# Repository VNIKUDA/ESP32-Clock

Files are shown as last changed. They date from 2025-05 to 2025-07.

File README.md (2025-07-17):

#  ESP32 CLOCK

> This project was made with **PlatfornIO** VSCode extension. If you're using **Arduino IDE**, please copy code from `src/main.py`.

This project was attempt to reverse engineer this clock and recreate my version using ESP32 microcontroller.

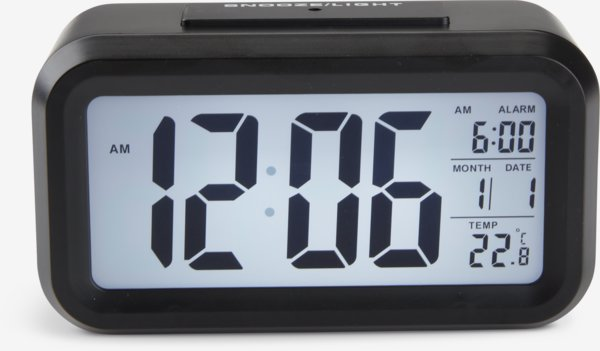
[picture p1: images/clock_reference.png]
Clock reference image


And here is my version:
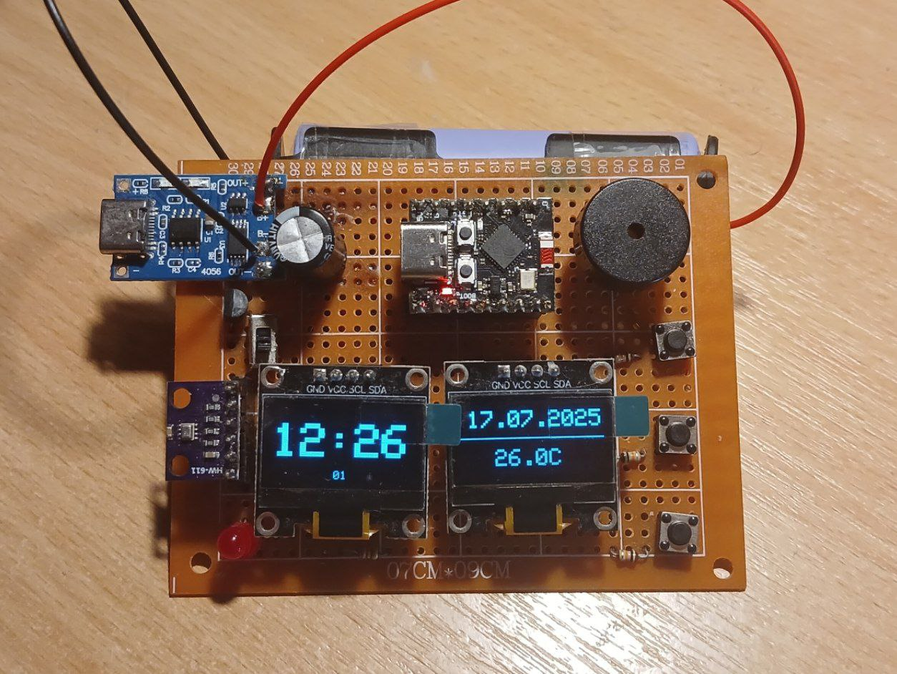
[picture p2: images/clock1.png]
Clock

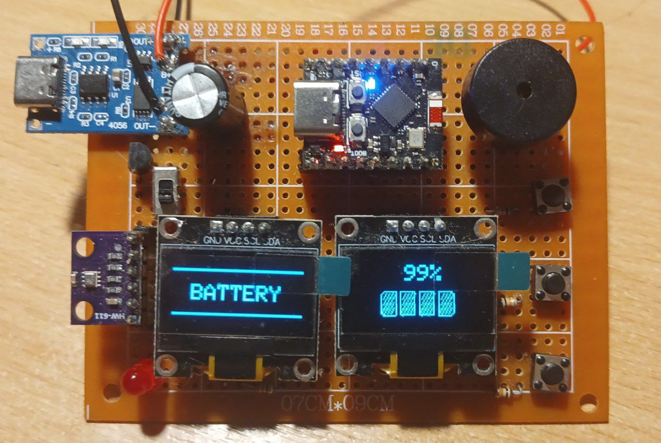
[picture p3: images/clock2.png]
Clock

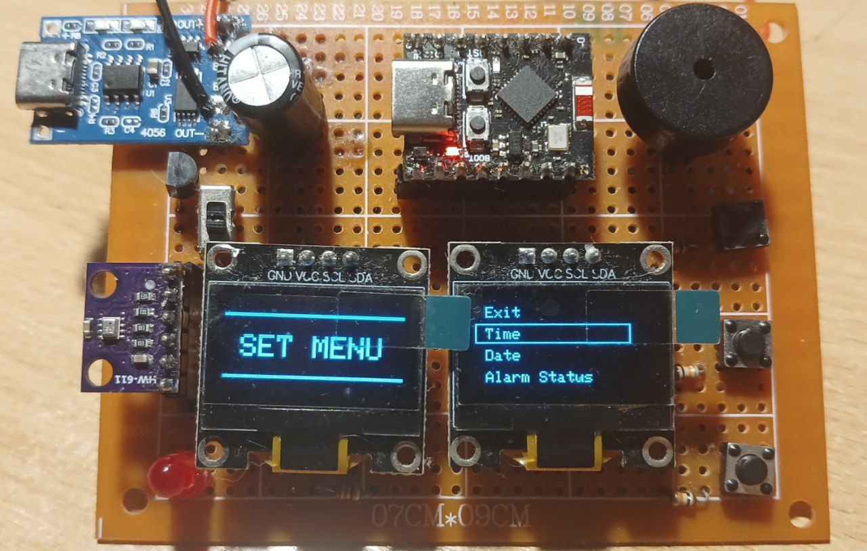
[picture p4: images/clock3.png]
Clock

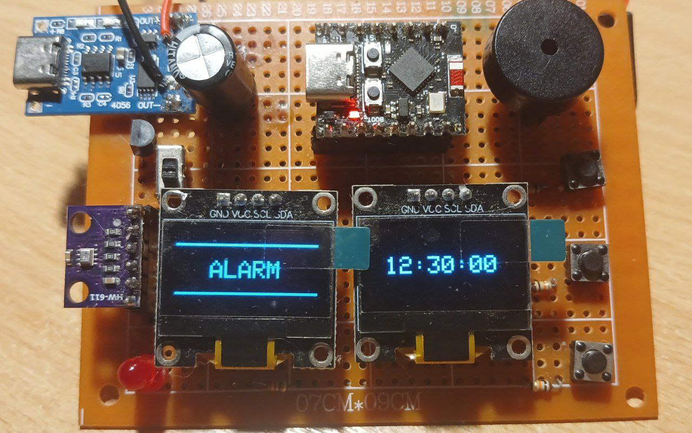
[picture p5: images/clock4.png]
Clock

It may look not as pretty as reference, but it works just as the other and has additional features!

## What functionality does it have?
 - **Three buttons for controll**: UP, SET, DOWN.

 - **Charging module**. While charging the red indicator will light up. Once charge, the red one will turn off and green will light up instead.

 - **Showing time and date**.

 - **Reading temperature** in the room/surrounding area.

 - **Alarm**. It will play a little alarm sound where the time comes.

 - **Sleep**. To preserve battery and not to annoy you with bright light during your sleep, you can set time when clock will go into sleep. You can still check time by waking up using SET button and screen will show the time for 10 seconds.

 - **Settings menu**. Here you can:
    - Set current time and date
    - Set alarm time and turn it off/on
    - Set sleep start and end time + turn on/off the sleep.
    - Turn on or off seconds displayment
    - Check battery charge (aproximate)

 **NOTE**: PLEASE DON'T PLUG CHARGING MODULE AND ESP32 USB-C PORT AT THE SAME TIME! IT WILL CAUSE DAMAGE TO THE CHIP!<br/>
## Technical specifications
 - **Current draw**: **~8 mA** in normal mode and **~0.07 mA** in sleep/
 - **Battery**: 18650 3.7V Li-on battery. 
 - **Battery capacity**: 2000mAh (but you can change to your needs).
 - **Time between charging**: **~8 days** and **~12.5** days using sleep mode for 9 hours a day.
 - **Time drift**: clock losses **1 minute each 5 days**.

**NOTE**: Because this clock doesn't uses external RTC module, it has unavoidable time drift. Please be aware.

## Requirenments
 | Part | Quantity |
 | -----|:-------:|
 | ESP32-C3 SUPER MINI | 1 |
 | SSD1306 OLED 128x64 display | 2 |
 | BMP280 HW-611 sensor | 1 |
 | TP4056 charging module | 1 |
 | 18650 3.7V 2000mAh battery | 1 |
 | 18650 battery case | 1 |
 | Buzzer | 1 |
 | Red LED | 1 |
 | Push-button | 3 |
 | Slide-switch | 1 |
 | 10kOm Resistor | 5 |
 | 220Om Resistor | 1 |
 | HT7833 3.3V TO-92 LDO | 1 |
 | 1000uF Electrolytic capacitor | 1 |
 | 100nF Ceramic capacitor | 1 |

 **Optional:** You can use female pin header to connect esp32, displays sensor and buzzer to be able to reuse this assets in other projects or to replace if something fails. You can buy a one or two 40-pin one and chop it to pieces of all sizes you need or buy this female pin connectors.
 |Part | Quantity|
 |-----|:-------:|
 | 1-pin female pin connector | 2 |
 | 4-pin female pin connector | 2 |
 | 6-pin female pin connector | 1 |
 | 8-pin female pin connector | 2 |

 1-pin are used for Buzzer, 4-pin for displays, 6-pin for temperature sensor and 8-pin for esp32.

## Schematic
Here you can download <a download href="./Clock_Alarm.fzz">fritzing schematic</a> to build clock yourself.

**Schematic**
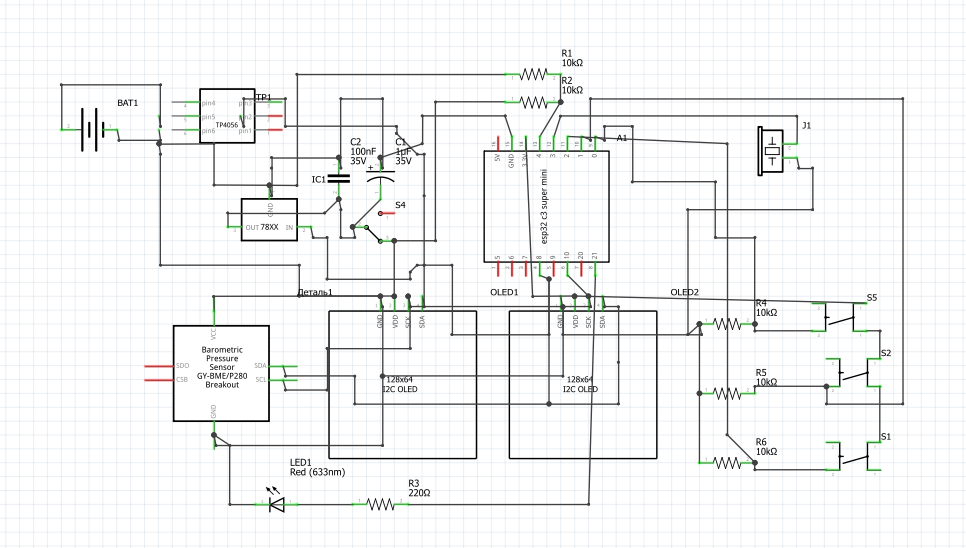
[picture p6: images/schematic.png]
Schematic


**Prototype view**
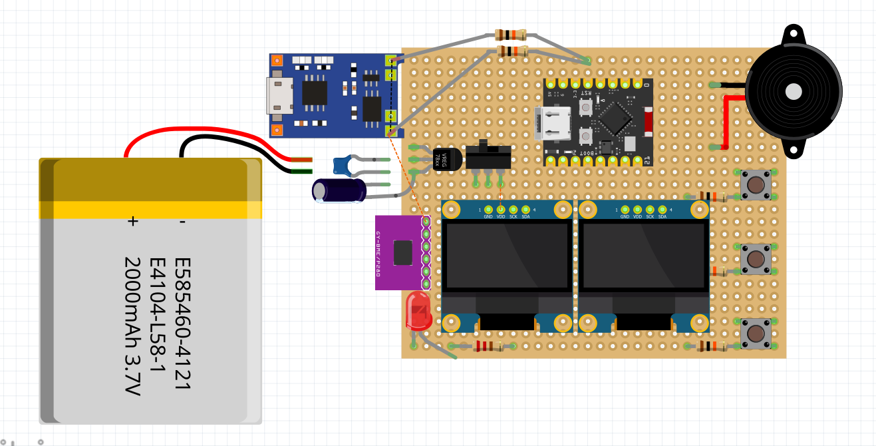
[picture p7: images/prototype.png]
Prototype view


**Prototype view with wires**
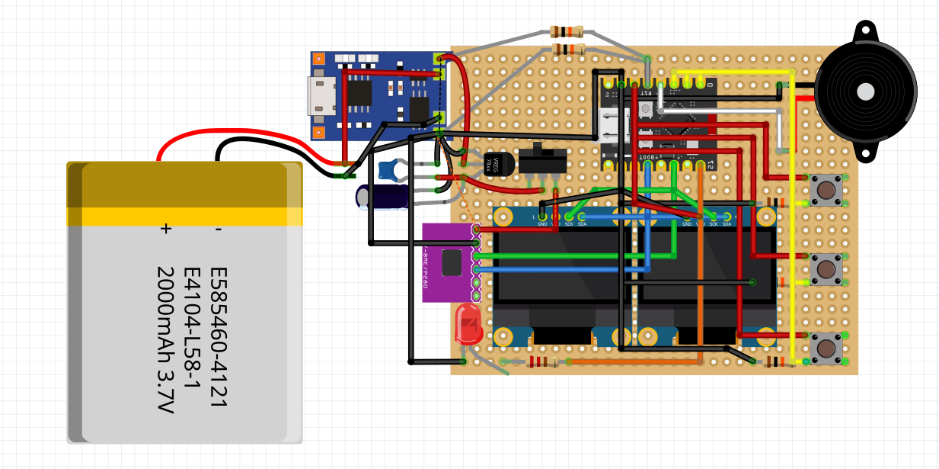
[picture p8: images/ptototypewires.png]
Prototype view with wires


**ESP32 C3 SUPER-MINI PINOUT**
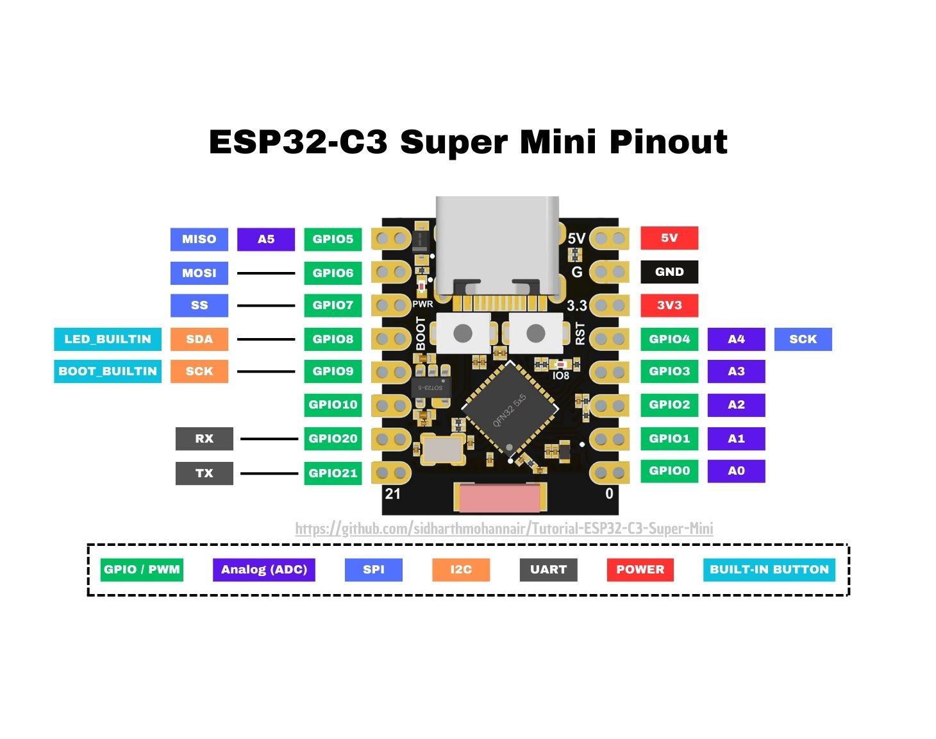
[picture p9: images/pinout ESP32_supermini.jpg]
Pinout


----

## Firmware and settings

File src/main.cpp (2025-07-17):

// --------- ГОДИННИК ---------
//
// Що він може?
//    У годинника є три екрани: годинник, меню та налаштування.
//    Є будильник з сигналом. Можна налаштовувати час, дату, час будильника та
//    його стан (включений або виключений) і багато іншого
//
// Як вийти в меню?
//    Щоб потрапити на екран меню треба затиснути кнопку SET.
//    Звідти можна виконати наступні дії:
//      - Повернутись на годинник, тобто вийти з меню.
//      - Налаштувати поточний час
//      - Налаштувати поточну дату
//      - Налаштувати статус будильника
//      - Налаштувати час будильника
//      - Налаштувати статус режима сну
//      - Налаштувати початок сну
//      - Налаштувати кінець сну
//      - Налаштувати відображення секунд
//      - Подивитись заряд батареї
//    Між діями можна переміщатись на кнопки UP та DOWN.
//    Щоб підтвердити будь-яку дію в меню треба затиснути кнопку SET.
//    Після вибору дії вас перенесе не меню налаштування (або на годинник
//    якщо ви вибрали вийти).
//
// Як подивитись час в режимі сну?
//    Для цього натисніть на кнопку SET, і екран покаже вам 
//    час на момент включення протягом 10 секунд, після чого годинник знову засне.
// 
// 
// ----------------------------

// Бібліотеки
#include <Adafruit_SSD1306.h>
#include <Adafruit_BMP280.h>
#include <Wire.h>
#include <esp_pm.h>

// Змінні для відстеження зміни часу
long currentTime, previousTime;

// Мілісекунд в секунді
#define MILLI_TO_SECOND 1000.0
#define MICRO_TO_SECOND 1000000.0

// Через шуми та неідеальності в кварцовому резонаторі, функція millis()
// дуже відстає від реального часу. Тому в випадку використання
// годинника без зовнішього RTC модуля використовуються мултіплаєри щоб
// приблизно отримати реальний час. На жаль, дрифт буде присутнім завжди.
// При цих налаштувань годинник відстає на 1 хвилину через 4.5 днів.
// Використовувався алгоритм двійкового пошуку для знаходження оффсетів.
#define TIME_OFFSET 1.002181676275
#define SLEEP_TIME_OFFSET 1.00268167625

// Заряд батареї та її напруга (приблизна)
float voltage = 0;
int charge = 0;

#define DISCHARGED_BATTERY_VOLTAGE 3.3
#define CHARGED_BATTERY_VOLTAGE 4.1

// Режим (годинник + будильник, вибір налаштування, меню налаштування)
int mode;

// Поточна температура
String temperature;

// Налаштування будильника
bool alarm_on = true;
bool alarm_playing = false;
int alarm_hours = 7, alarm_minutes = 30, alarm_seconds = 0;

// Налаштування часу відключення
bool sleep_on = true;
bool sleeping = false;
int sleep_start_hours = 12, sleep_start_minutes = 0, sleep_start_seconds = 5;
int sleep_end_hours = 12, sleep_end_minutes = 0, sleep_end_seconds = 30; 

// Налаштування поточного часу годинника
float hours = 12, minutes = 0, seconds = 0;

// Налаштування для відображення секунд
bool display_seconds = false;

// Налаштування поточної дати
int date = 17, month = 7, year = 2025;

// Список днів в кожному місяці (для лютого йде перевірка в коді)
int monthDays[] = {
    31, // Січень
    28, // Лютий
    31, // Березень
    30, // Квітень
    31, // Травень
    30, // Червень
    31, // Липень
    31, // Серпень
    30, // Вересень
    31, // Жовтень
    30, // Листопад
    31  // Грудень
};

// Список налаштувань та дій для меню вибору налаштування
String options[] = {
    "Battery", "Display Seconds", "Sleep End", "Sleep Start", "Sleep Status", "Alarm Time", "Alarm Status", "Date", "Time", "Exit"};
int options_count = sizeof(options) / sizeof(String);
int menu_option = options_count - 1; // Поточний вибір
int option_cursor = options_count - 1; // Індекс найвищої опції на екрані

// Список полів для кожного меню налаштування
float *timeFields[] = {&hours, &minutes, &seconds};
int *dateFields[] = {&date, &month, &year};
int *alarmFields[] = {&alarm_hours, &alarm_minutes, &alarm_seconds};
int *sleepStartFields[] = {&sleep_start_hours, &sleep_start_minutes, &sleep_start_seconds};
int *sleepEndFields[] = {&sleep_end_hours, &sleep_end_minutes, &sleep_end_seconds};

int fieldCount[] = {0, 1, 3, 3, 1, 3, 1, 3, 3}; // Кількість полів на кожному меню налаштування
int current_field = 0;           // Поточне поле налаштування

// Поріг зарахування натиску кнопки на певну дію
#define MENU_ACTIVATION_THRESHOLD 1000 // Час для викликання SET MENU та підтвердження вибору\налаштувань
#define ACTION_THRESHOLD 100           // Час для зарахування натиску кнопки

// Клас кнопки (для легшості роботи з ними та зменшеню повторення коду)
class Button
{
private:
    int pin; // Цифровий порт, до якого підключена кнопка

    bool clicked = false; // Чи кнопка натиснута (тільк перший раз)
    bool hold = false;    // Чи кнопка затиснута
    bool pressed = false; // Чи кнопка натиснута (взагалі)
    int pressedTime = 0;  // Час з початку натиску кнопки в мілісекундах

    int action = LOW;       // Сигнал з цифрового порта
    int lastAction = LOW;   // Минулий сигнал з цифрового порта
    int lastActionTime = 0; // Час минулої зміни сигналу з цифрового порта

public:
    // Конструктор. Приймає цифровий порт, до якого приєднана кнопка
    Button(int pin)
    {
        this->pin = pin;
    };

    // Ініціалізація кнопки шляхом встановлення режиму роботи порта на вхід\зчитування
    void init()
    {
        pinMode(pin, INPUT);
    }

    // Оновлення данних про кнопку
    void update()
    {
        // Читання поточного сигналу з цифрового порта
        action = digitalRead(this->pin);

        // Якщо сигнал відрізняється від попереднього, то оновити час останої дії
        // кнопки та останього сигналу.
        if (action != lastAction)
        {
            lastAction = action;
            lastActionTime = currentTime;
        }

        // Якщо поточний сигнал високий (тобто кнопка затиснута) і час з останьої дії
        // є більшим за час для зарахування натиску
        if (action == HIGH && currentTime - lastActionTime >= ACTION_THRESHOLD)
        {

            // Якщо це вже друга обробка, то кажемо що кнопка вже затиснута, а не натиснута
            // перевіряти коли кнопка була натиснута, а не затиснута
            if (this->hold == false && this->clicked == true)
            {
                this->hold = true;
                this->clicked = false;
            }
            // Перевіряємо чи це перша обробка, для того щоб мати змогу
            if (this->pressed == false && this->clicked == false)
            {
                this->clicked = true;
                this->hold = false;
            }

            // Кажемо, що кнопка взагалі натиснута (не важливо чи затиснута чи натиснута вперше)
            this->pressed = true;
        }
        // Якщо ні, то кажемо що кнопка взагалі не натиснута і час натиску відповідно
        // дорівнює 0
        else
        {
            this->pressed = false;
            this->pressedTime = 0;
            this->hold = false;
            this->clicked = false;
        }

        // Якщо конпка взагалі натиснута, то відслідковуємо час скільки вона є натиснутою
        if (this->pressed)
        {
            pressedTime = currentTime - lastActionTime;
        }
    }

    // Методи-інтерфейс для отримання данних з кнопки

    bool getPressed()
    {
        return this->pressed;
    }

    int getPressedTime()
    {
        return this->pressedTime;
    }

    bool getClicked()
    {
        return this->clicked;
    }

    bool getHold()
    {
        return this->hold;
    }

    int getPin() {
        return this->pin;
    }

    // Скидання стану кнопки, крім стану натиску взагалі. Використовується для
    // того, щоб, наприклад, коли користувач затиснув на вихід в меню його одразу не
    // перекинуло назад в меню (якщо стан затиску і час натиску залишиться такими ж,
    // тоді програма подумає що користувач спеціально затиснув кнопку на екрані годиника
    // і хоче в меню)
    void reset()
    {
        this->pressedTime = 0;
        this->hold = false;
        this->clicked = false;
    }
};

// ДисплеЇ
Adafruit_SSD1306 leftOled(128, 64, &Wire);
Adafruit_SSD1306 rightOled(128, 64, &Wire);

// Датчик температури
Adafruit_BMP280 bmp;

// Кнопки
Button upButton(0);
Button setButton(1);
Button downButton(2);

#define PIEZO 3 // Цифровий порт для пієзодинаміка
#define CHARGE_LED 21

// Функція для відмальовки вертикальної стрілки
void drawVArrow(int x, int y, int w, int h, int thickness, int direction, Adafruit_SSD1306 *display, int color = WHITE)
{
    for (int i = 0; i < thickness; i++)
    {
        if (direction == 1)
        {
            display->drawLine(x, y + h + i, x + w / 2, y + i, color);
            display->drawLine(x + w / 2, y + i, x + w, y + h + i, color);
        }
        else
        {
            display->drawLine(x, y + i, x + w / 2, y + h + i, color);
            display->drawLine(x + w / 2, y + h + i, x + w, y + i, color);
        }
    }
}

// Функція відмальовки наполовину закругленого прямокутника
void drawRoundRect(int x, int y, int w, int h, int rounding, int direction, Adafruit_SSD1306 *display, int color = WHITE) {
    if (direction == 1) {
        display->drawCircleHelper(x + rounding, y + rounding, rounding, 1, color);
        display->drawCircleHelper(x + rounding, y + h - rounding, rounding, 8, color);
        display->drawFastHLine(x + rounding, y, w - rounding, color);
        display->drawFastHLine(x + rounding, y + h, w - rounding, color);
        display->drawFastVLine(x, y + rounding, h - rounding * 2 + 1, color);
        display->drawFastVLine(x + w, y, h, color);
    } else {
        display->drawCircleHelper(x + w - rounding, y + rounding, rounding, 2, color);
        display->drawCircleHelper(x + w - rounding, y + h - rounding, rounding, 4, color);
        display->drawFastHLine(x, y, w - rounding + 1, color);
        display->drawFastHLine(x, y + h, w - rounding + 1, color);
        display->drawFastVLine(x + w, y + rounding, h - rounding * 2 + 1, color);
        display->drawFastVLine(x, y, h, color);
    }
}

// Функція відмальовки патерну закраски 
void drawPattern(int x, int y, int w, int h, int lines, Adafruit_SSD1306 *display, int color = WHITE) {
    int stepX = w / lines;
    int stepY = h / lines;
    for (int i = 1; i <= lines; i++) {
        display->drawLine(x + 2, y + stepY * i + 2, x + stepX * i + 2, y + 2, color);
        display->drawLine(x + w - 2, y + h - stepY * i - 2, x + w - stepX * i - 2, y + h - 2, color);
    }
}


int clamp(int value, int maximum, int minimum) {
    return max(min(maximum, value), minimum);
}

// Функція для перевірки чи поточний час знаходиться 
// в діапазоні режима сна.
bool timeInRange() {
    // Розраховуєтсься час та межі в секундах
    float total = hours * 3600 + minutes * 60 + seconds;
    int startTotal = sleep_start_hours * 3600 + sleep_start_minutes * 60 + sleep_start_seconds;
    int endTotal = sleep_end_hours * 3600 + sleep_end_minutes * 60 + sleep_end_seconds;

    // Перевірка. Якщо початок менше кінця (тобто діапазон знаходиться в одній добі)
    // то перевіряємо чи час в цьому проміжку.
    if (startTotal <= endTotal) {
        return startTotal <= total and total <= endTotal;
    } else { // Якщо інакше (тобто діапазон розподілен між двома добами)
        return startTotal <= total or total <= endTotal; 
    }
}

// ЕКРАН ГОДИННИКА
// Оновлює час
void timeUpdate()
{
    if (seconds >= 60)
    {
        seconds = 0;
        minutes += 1;
    }
    if (minutes >= 60)
    {
        minutes = 0;
        hours += 1;
    }
}

// Оновлює дату
void dateUpdate()
{
    if (hours >= 24)
    {
        hours = 0;
        date += 1;
        if (month == 2)
        {
            monthDays[1] = (year % 4 == 0) ? 29 : 28;
        }
    }
    if (date > monthDays[month - 1])
    {
        date = 1;
        month += 1;
    }
    if (month > 12)
    {
        month = 1;
        year += 1;
    }
}

// Оновлення годиника в цілому
void clockUpdate()
{
    // Якщо кнопка меню затиснута, то перейти на екран меню
    if (setButton.getHold() && setButton.getPressedTime() >= MENU_ACTIVATION_THRESHOLD && !sleeping)
    {
        menu_option = options_count - 1;
        mode = 1;
        setButton.reset();
    }

    // Розрахунок скільки секунд пройшло з минулого оновлення
    float deltaTime = currentTime - previousTime;
    // Оффест
    double time_offset = (sleeping and !setButton.getClicked()) ? SLEEP_TIME_OFFSET : TIME_OFFSET;

    seconds += (deltaTime / MILLI_TO_SECOND) * time_offset;

    // Оновлення даних годиника
    timeUpdate();
    dateUpdate();

    // Керування будильником
    // Якщо булильник грає та кнопка меню натиснута, то зупинити будильник
    if (setButton.getPressed() && alarm_playing)
    {
        alarm_playing = false;
        setButton.reset();
    }
    // Якщо час співпадає з часом будильника, то запустити будильник
    if ((int)seconds == alarm_seconds && minutes == alarm_minutes && hours == alarm_hours && alarm_on)
        alarm_playing = true;

    // Ввімкнення та вимкення пієзодинаміка для створення того самого
    // пікання :)
    if (alarm_playing && currentTime % 500 > 250)
        analogWrite(PIEZO, 150);
    else
        analogWrite(PIEZO, 0);

    if (alarm_playing) {
        esp_sleep_enable_timer_wakeup(0.2 * MICRO_TO_SECOND);
        gpio_wakeup_disable((gpio_num_t)setButton.getPin());
        leftOled.ssd1306_command(SSD1306_DISPLAYON);        
        rightOled.ssd1306_command(SSD1306_DISPLAYON);
        sleeping = false;
    }

    previousTime = currentTime;
}

// Відмальовка екрану годиника з будильником
void displayClock()
{
    if (!alarm_playing)
    {
        leftOled.setTextSize(4);
        rightOled.setTextSize(2);

        for (int i = 0; i < 2; i++)
        {
            leftOled.setCursor(2 + i, 16);
            leftOled.print((hours < 10) ? '0' + String((int)hours) : String((int)hours));
            leftOled.print(":");
            leftOled.print((minutes < 10) ? '0' + String((int)minutes) : String((int)minutes));
        }

        if (display_seconds) {
            leftOled.setTextSize(1);
            leftOled.setCursor(56, 56);
            leftOled.print((seconds < 10) ? '0' + String((int)seconds) : String((int)seconds));
        }

        rightOled.setCursor(7, 8);
        rightOled.print((date < 10) ? '0' + String(date) : String(date));
        rightOled.print(".");
        rightOled.print((month < 10) ? '0' + String(month) : String(month));
        rightOled.print(".");
        rightOled.print(year);

        rightOled.drawFastHLine(0, 31, 128, WHITE);

        // Зчитування температури 2 рази на хвилину 
        if (seconds == 0 or seconds == 30 or sleeping) {
            String temperature = String(bmp.readTemperature());
            temperature.remove(temperature.length() - 1);
        }

        rightOled.setCursor(31, 41);
        rightOled.print(temperature);
        rightOled.print("C");
    }
    else
    {
        leftOled.setTextSize(2);
        rightOled.setTextSize(2);

        leftOled.drawRect(4, 12, 120, 2, WHITE);
        leftOled.setCursor(33, 26);
        leftOled.print("ALARM");
        leftOled.drawRect(4, 52, 120, 2, WHITE);

        rightOled.setCursor(15, 26);
        rightOled.print((alarm_hours < 10) ? '0' + String(alarm_hours) : String(alarm_hours));
        rightOled.print(":");
        rightOled.print((alarm_minutes < 10) ? '0' + String(alarm_minutes) : String(alarm_minutes));
        rightOled.print(":");
        rightOled.print((alarm_seconds < 10) ? '0' + String(alarm_seconds) : String(alarm_seconds));
    }
}

// ЕКРАН МЕНЮ
// Оновлення та обробка кнопок в меню
void menuUpdate()
{
    // Піднятися вверх по списку дій
    if (upButton.getClicked() && menu_option < options_count - 1) {
        menu_option++;
        if (menu_option > option_cursor) option_cursor++;
    }

    // Спуститися вниз по списку дій
    if (downButton.getClicked() && menu_option > 0) {
        menu_option--;
        if (menu_option <= option_cursor - 4) option_cursor--;
    }

    // Якщо кнопка затиснута (тобто користувач підтвердив вибір)
    if (setButton.getHold() && setButton.getPressedTime() >= MENU_ACTIVATION_THRESHOLD)
    {
        // Скидаємо стан кнопки
        setButton.reset();

        // Якщо вибір був вийти, топ повертаємось на годинник
        if (menu_option == options_count - 1)
        {
            mode = 0;
        }
        // Якщо ні, то переходимо на екран налаштувань
        else
        {
            mode = 2;
            current_field = 0;
        }

        // Оновлення часу (потрібно, щоб годинник не збився поки він у меню)
        float deltaTime = currentTime - previousTime;
        float deltaSeconds = deltaTime / MILLI_TO_SECOND;
        while (deltaSeconds > 60)
        {
            float timeToMinute = 60.0 - seconds;
            deltaSeconds -= timeToMinute;
            seconds += timeToMinute;
            timeUpdate();
            dateUpdate();
        }
        seconds += deltaSeconds;

        if (seconds > 60)
        {
            deltaSeconds = seconds - 60;
            timeUpdate();
            dateUpdate();
            seconds += deltaSeconds;
        }
        timeUpdate();
        dateUpdate();

        previousTime = currentTime;
    }
}

// Відмалювати екран меню
void displayMenu()
{
    leftOled.setTextSize(2);
    rightOled.setTextSize(1);

    leftOled.drawRect(4, 12, 120, 2, WHITE);
    leftOled.setCursor(15, 26);
    leftOled.print("SET MENU");
    leftOled.drawRect(4, 52, 120, 2, WHITE);

    for (int option = options_count - 1; option >= 0; option--)
    {
        if (option > option_cursor - 4 and option <= option_cursor) {
            rightOled.setCursor(12, 8 + 14 * (options_count - 1 - option - (options_count - 1 - option_cursor)));
            rightOled.print(options[option]);
        }
    }

    rightOled.drawRect(5, 5 + 14 * (options_count - 1 - menu_option - (options_count - 1 - option_cursor)), 104, 13, WHITE);
}
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
void loop()
{
    // Час від запуску Arduino
    currentTime = millis();

    // Оновлення кнопок
    setButton.update();
    downButton.update();
    upButton.update();

    // Очищення дисплею
    leftOled.clearDisplay();
    rightOled.clearDisplay();
    
    // Якщо режим сну включений, перевіряємо чи час є в діапазоні 
    // цього режиму і зберагіємо цю інформацію
    if (sleep_on) {
        sleeping = timeInRange();

        // Якщо час знаходиться в діапазоні режима сну і зараз головний 
        // екран (годинник + будильник)
        if (sleeping and mode == 0) {
            esp_sleep_enable_timer_wakeup(10 * MICRO_TO_SECOND); // Затримка між оновленням тепер 10 секунд

            // Якщо кнопку SET настиснуто, то включити екран на одну ітерацію
            if (setButton.getClicked()) {
                gpio_wakeup_disable((gpio_num_t)setButton.getPin());
                leftOled.ssd1306_command(SSD1306_DISPLAYON);                
                rightOled.ssd1306_command(SSD1306_DISPLAYON);
            } else { // Інакше виключаємо екран
                gpio_wakeup_enable((gpio_num_t)setButton.getPin(), GPIO_INTR_HIGH_LEVEL);
                leftOled.ssd1306_command(SSD1306_DISPLAYOFF);                
                rightOled.ssd1306_command(SSD1306_DISPLAYOFF);
                setButton.reset();
            }
        } else { // Якщо ми в іншому вікні або ще не час спати, скидаємо параметри до звичних
            esp_sleep_enable_timer_wakeup(0.2 * MICRO_TO_SECOND);
            gpio_wakeup_disable((gpio_num_t)setButton.getPin());
            leftOled.ssd1306_command(SSD1306_DISPLAYON);            
            rightOled.ssd1306_command(SSD1306_DISPLAYON);
        }
    } else { // На всякий випадок якщо режим сну виключений, скинути всі параметри до звичних
        esp_sleep_enable_timer_wakeup(0.2 * MICRO_TO_SECOND);
        gpio_wakeup_disable((gpio_num_t)setButton.getPin());
        leftOled.ssd1306_command(SSD1306_DISPLAYON);        
        rightOled.ssd1306_command(SSD1306_DISPLAYON);
        sleeping = false;
    }

    


    // Режими\екрани програми
    switch (mode)
    {
    case 0: // Годинник + будильник
        
        clockUpdate();
        
        // Відмальовуємо годинник тільки коли не спимо
        if (!sleeping or setButton.getClicked()) displayClock();

        break;
    case 1: // Меню
        menuUpdate();

        displayMenu();
        break;
    case 2: // Налаштування
        actionMenuUpdate();

        displayActionMenu();
        break;
    }    
    
    // Оновлення дисплею
    leftOled.display();
    rightOled.display();

    // Приблизна напруга акамулятора
    voltage = ((analogRead(4) / 4095.0) * 3.3) - 0.29;
    voltage *= 2.02;

    // Приблизний заряд акамулятора і відфільтрований 
    // заряд (максимум 100% та мінімум 0%)
    charge = round((voltage - DISCHARGED_BATTERY_VOLTAGE) / (CHARGED_BATTERY_VOLTAGE - DISCHARGED_BATTERY_VOLTAGE) * 100);
    charge = clamp(charge, 100, 0);

    // Якщо заряд менше 1%, виключаємо пристрій
    // в Deep Sleep споживання енергії дуже мале, тому 
    // він майже виключений
    if (charge < 1) {
        esp_deep_sleep_start();
    }
    // Якщо заряд менше п'яти, кожні 500 мілісекунд блимати світлодіодом
    else if (charge < 5 && currentTime % 1000 < 500) {
        analogWrite(CHARGE_LED, 80);
    } else {
        digitalWrite(CHARGE_LED, LOW);
    }

    // Затримка перед наступною ітерацією програми
    esp_light_sleep_start();
}

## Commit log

2025-05-29 In case of data loss
2025-07-16 Battery menu added. Menu scroll created.
